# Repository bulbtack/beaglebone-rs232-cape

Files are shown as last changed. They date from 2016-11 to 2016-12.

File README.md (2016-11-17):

# BeagleBone RS-232 Cape #

A cape for the BeagleBone Black (and compatible derivatives) that adapts four of the onboard UARTs (UART1, UART2, UART4, and UART5) for use with RS-232 usage.
The cape also brings out UART0 from J1 to another FTDI compatible header.

## The Bill of Materials ##

Designator                              | Value                       | Size
----------------------------------------|-----------------------------|--------------
U1, U2                                  | ST232ECTR                   | TSSOP16 
C1, C2, C3, C4, C5, C6, C7, C8, C9, C10 | .1 uF X7R                   | 0402
P1, P2, P4, P5                          | Male Right Angle Header     | .1" 2x5
P3                                      | Female Socket               | .1" 1x6
P6                                      | Male Right Angle Header SMT | .1" 1x6
P8, P9                                  | Female Socket               | .1" 2x23

https://octopart.com/bom-tool/arnFMVWq

## License ##

This project is licesned under the CERN Open Hardware License 1.2.

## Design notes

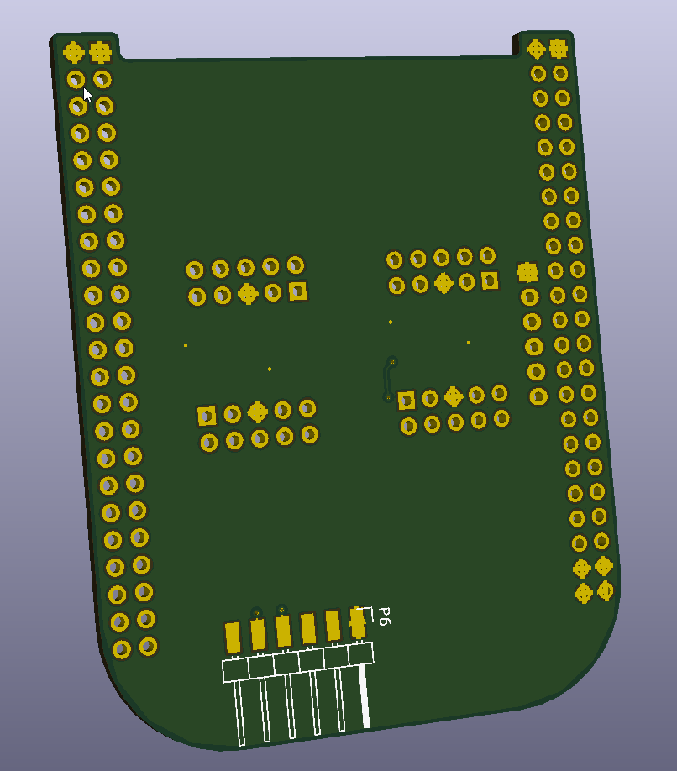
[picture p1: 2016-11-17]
images/beaglebone-rs232-cape-pcb-back.png

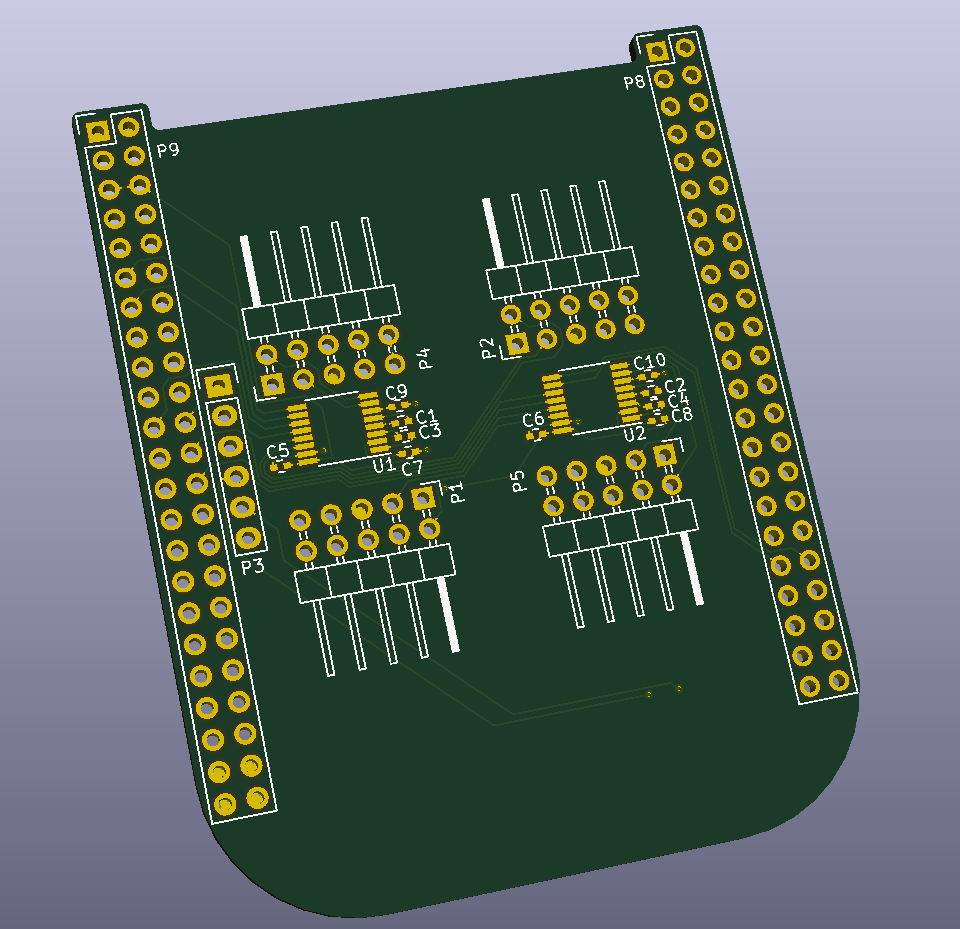
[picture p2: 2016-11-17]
images/beaglebone-rs232-cape-pcb-front.png

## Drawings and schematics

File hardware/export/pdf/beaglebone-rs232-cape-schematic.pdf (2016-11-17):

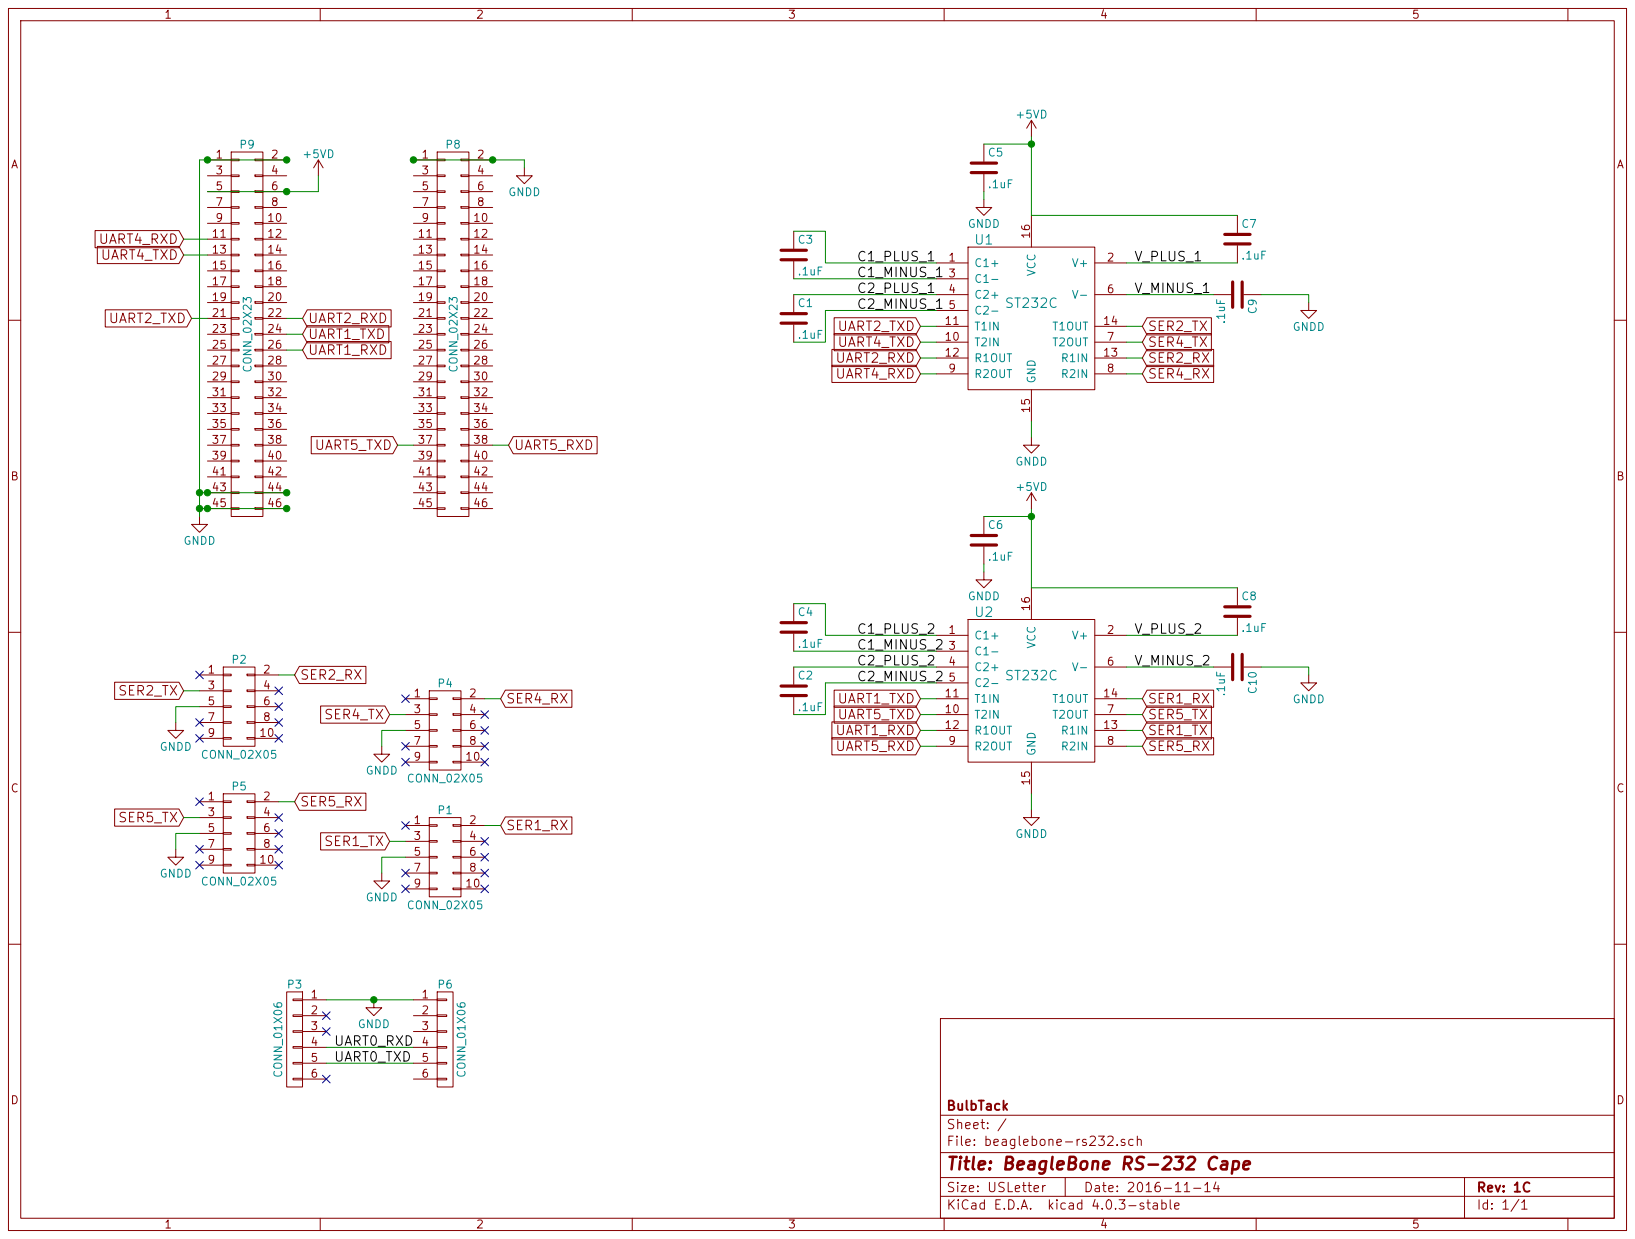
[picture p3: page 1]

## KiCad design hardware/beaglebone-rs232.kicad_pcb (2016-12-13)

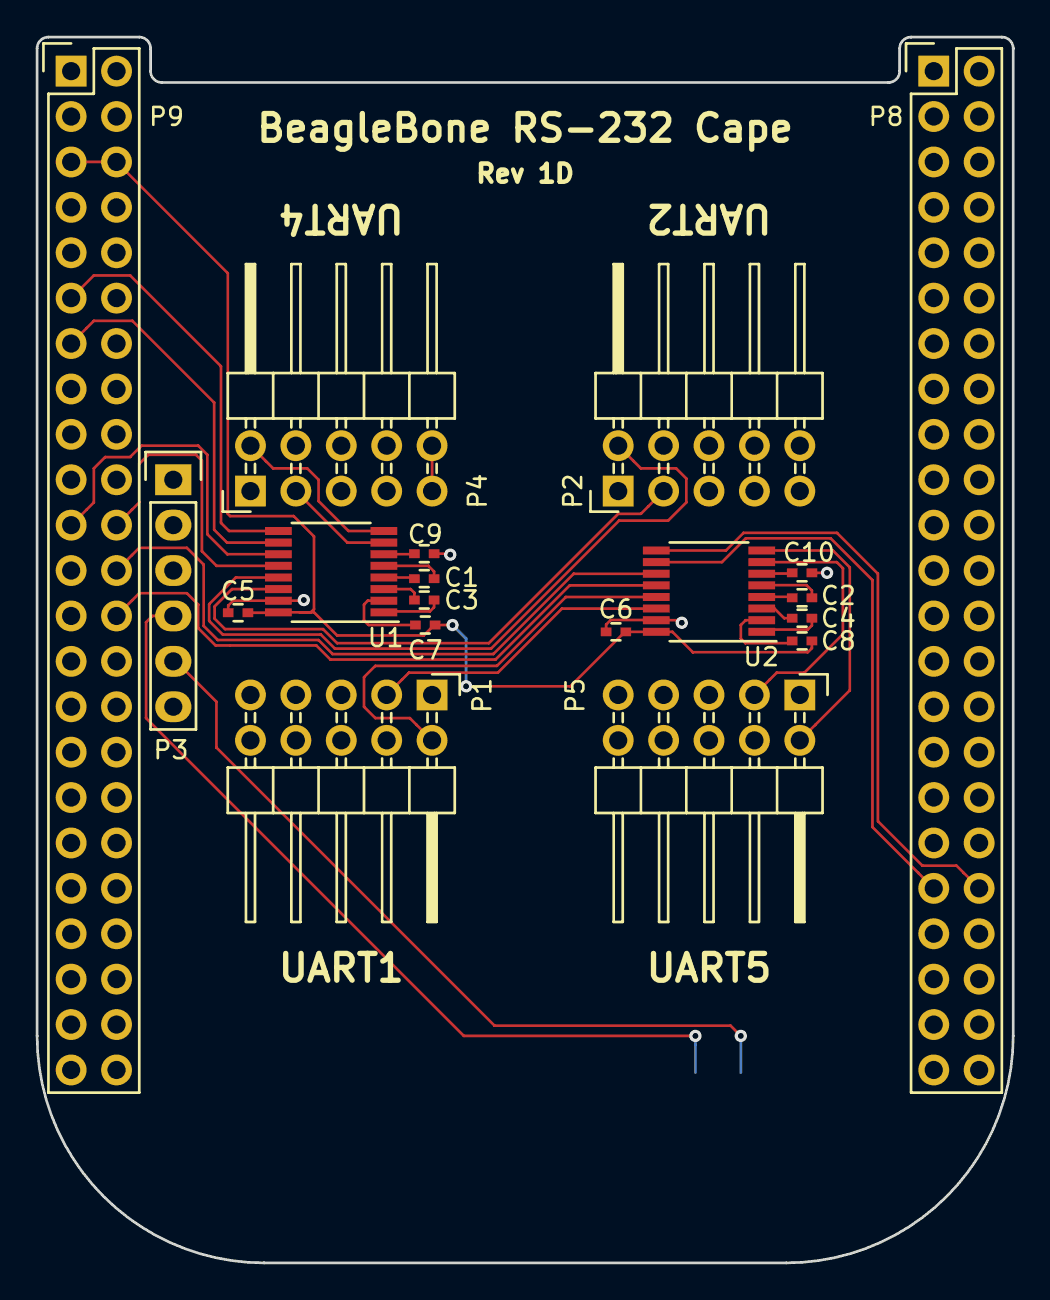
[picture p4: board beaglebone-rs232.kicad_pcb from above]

Board: 2 copper layers, 54.6 x 68.6 mm, 20 parts (1 on the bottom side), 32 nets.

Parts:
C1, C2, C3, C4, C5, C6, C7, C8, C9, C10: .1uF; C_0402
P1, P2, P4, P5: CONN_02X05; Pin_Header_Angled_2x05
P3: CONN_01X06; Pin_Header_Straight_1x06
P6: CONN_01X06; Pin_Header_Angled_1x06_SMT
P8, P9: CONN_02X23; Pin_Header_Straight_2x23
U1, U2: ST232C; TSSOP-16_4.4x5mm_Pitch0.65mm

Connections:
+5VD: C5.1, C6.1, C7.1, C8.1, P9.5, P9.6, U1.16, U2.16
/C1_MINUS_1: C3.2, U1.3
/C1_MINUS_2: C4.2, U2.3
/C1_PLUS_1: C3.1, U1.1
/C1_PLUS_2: C4.1, U2.1
/C2_MINUS_1: C1.2, U1.5
/C2_MINUS_2: C2.2, U2.5
/C2_PLUS_1: C1.1, U1.4
/C2_PLUS_2: C2.1, U2.4
/UART0_RXD: P3.4, P6.4
/UART0_TXD: P3.5, P6.5
/V_MINUS_1: C9.2, U1.6
/V_MINUS_2: C10.2, U2.6
/V_PLUS_1: C7.2, U1.2
/V_PLUS_2: C8.2, U2.2
GNDD: C5.2, C6.2, C9.1, C10.1, P1.5, P2.5, P3.1, P4.5, P5.5, P6.1, P8.1, P8.2, P9.1, P9.2, P9.43, P9.44, P9.45, P9.46, U1.15, U2.15
SER1_RX: P1.2, U2.13
SER1_TX: P1.3, U2.14
SER2_RX: P2.2, U1.13
SER2_TX: P2.3, U1.14
SER4_RX: P4.2, U1.8
SER4_TX: P4.3, U1.7
SER5_RX: P5.2, U2.8
SER5_TX: P5.3, U2.7
UART1_RXD: P9.26, U2.12
UART1_TXD: P9.24, U2.11
UART2_RXD: P9.22, U1.12
UART2_TXD: P9.21, U1.11
UART4_RXD: P9.11, U1.9
UART4_TXD: P9.13, U1.10
UART5_RXD: P8.38, U2.9
UART5_TXD: P8.37, U2.10
